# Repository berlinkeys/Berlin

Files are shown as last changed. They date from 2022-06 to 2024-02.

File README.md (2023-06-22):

# Berlin Keyboard

## Introduction
Berlin is a 120% Keyboard based on the design of the [Boston](https://github.com/bluepylons/Boston) keyboard. 
It has a lot of programmable Keys, runs QMK and all in all does everything you would like a keyboard to do.
It also features a big Display over the Numpad to enable more functions, like internal macros, status screens and custom graphics.

## Concept
The Inspiration for the Keyboard came directly from the Boston Keybaord. 
However, we wanted at least a 100% keyboard, including all the random keys only shady developers use.
Thats why we started redesigning the Boston, as it is both a good open source keyboard and a good starting point.
Dead space was never an option, so why not add an LCD instead of LED Indicators...

## Features
* 122-key in ISO configuration
* 127 local lighting zones
* 2 rotary encoders
* 3 SLIders
* optional lock LEDs 
* double sided and flippable debug connector
* Cherry MX Hotswap Ready
* Full-size Numpad
* Traditional 2x3 Ins/Del/Home/End/PgUp/PgDn navblock 
* Per Key RGBLED Lighting
* USB-C
* QMK and Vial support

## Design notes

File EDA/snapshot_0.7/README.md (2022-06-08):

# 0.7 dev version of PCB

***Important: This is a development branch of the keyboard. While in theory the PCB should work, something weird stuff called impedance and inductance always tries to mess up your projects. Also you wouldn't want this catching fire due to improper trace widths, would you? This is only v0.7 and due for a complete redesign. Don't be dumb, do not use this in prod (also not in testing for it is badly engineered).***

This directory is meant as a backup for the 0.7 version of the PCB. When the development on this version is complete, this will be deprecated and moved to branch ahead0.7.

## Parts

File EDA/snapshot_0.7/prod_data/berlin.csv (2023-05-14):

Comment | Designator | Footprint | LCSC
33 | R102,R101 | R_0805_2012Metric_Pad1.20x1.40mm_HandSolder | C328394
330 | R306,R307,R308 | R_Axial_DIN0207_L6.3mm_D2.5mm_P7.62mm_Horizontal | C17630
1.5A Polyfuse | F701 | Fuse_1812_4532Metric_Pad1.30x3.40mm_HandSolder | -
100 1% | R301,R703 | R_0805_2012Metric_Pad1.20x1.40mm_HandSolder | C17408
100k | R701 | R_0805_2012Metric_Pad1.20x1.40mm_HandSolder | C96346
100n | C707,C708,C725,C712,C102,C710,C727,C719,C101,C709,C723,C703,C721 | C_0805_2012Metric_Pad1.18x1.45mm_HandSolder | C2909631
100nF | C711 | C_0805_2012Metric_Pad1.18x1.45mm_HandSolder | C2909631
10k | R305,R302,R303,R304 | R_0805_2012Metric_Pad1.20x1.40mm_HandSolder | C17414
10u | C715,C724,C726,C706,C722,C720,C718 | C_1206_3216Metric_Pad1.33x1.80mm_HandSolder | C2985037
1M 1% | R702 | R_0805_2012Metric_Pad1.20x1.40mm_HandSolder | C17514
1N4148 | D43,D68,D105,D30,D83,D6,D35,D77,D10,D48,D103,D62,D93,D4,D63,D120,D9,D33,D31,D60,D91,D44,D110,D38,D84,D25,D53,D17,D51,D45,D59,D36,D119,D58,D47,D23,D111,D69,D126,D124,D2,D116,D99,D100,D125,D66,D19,D37,D80,D90,D61,D115,D32,D24,D28,D128,D75,D7,D113,D114,D64,D79,D107,D122,D94,D81,D74,D8,D5,D88,D21,D117,D26,D73,D82,D40,D98,D46,D56,D15,D41,D97,D67,D18,D87,D101,D112,D121,D96,D22,D78,D14,D57,D95,D13,D108,D54,D49,D16,D109,D118,D34,D106,D12,D39,D123,D76,D27,D703,D42,D71,D129,D104,D11,D89,D55,D85,D65,D92,D72,D70,D127,D52,D50,D3,D29,D20,D86 | D_SOD-123 | C14538
22uF | C717,C705,C701,C704 | C_1206_3216Metric_Pad1.33x1.80mm_HandSolder | C513771
330k 1% | R711 | R_0805_2012Metric_Pad1.20x1.40mm_HandSolder | C17629
4.7n | C714 | C_0805_2012Metric_Pad1.18x1.45mm_HandSolder | C1744
5.1k | R706,R705 | R_0805_2012Metric_Pad1.20x1.40mm_HandSolder | C27834
6.8uH | L701 | Sumida0624CDMCC | -
AP63203WU-7 | U702 | TSOT-23-6_HandSoldering | C780769
DTC123J | Q701 | SOT-23 | C2910218
L_Core_Ferrite | L1,L2,L702,L711 | L_0805_2012Metric_Pad1.15x1.40mm_HandSolder | C139247
LQFP100 | U501 | STM32F072VBT6 | C713240
MountingHole | HA201,HA204,HA202,HA203 | ToolingHole_1.152mm_(for_JLCPCB_SMT)
RB060M-60TR | D701 | D_SOD-123 | C114257
TE_2-84953-0_1x20-1MP_P1.0mm_Horizontal | J203 | TE_2-84953-0_1x20-1MP_P1.0mm_Horizontal | C362389
TYPE-C-31-M12_13 | J201 | TYPE-C-31-M-12 | C165948
USBLC6-2SC6 | U701 | SOT-23-6 | C2827654
WS2811 | LED1,16,LED1,1 | WS2811S | C3034986
WS2812B | LED3,11,LED3,2,LED7,5,LED2,10,LED3,6,LED2,8,LED7,2,LED1,7,LED1,2,LED4,8,LED5,11,LED1,6,LED7,7,LED4,5,LED3,7,LED7,6,LED5,14,LED6,9,LED1,10,LED5,9,LED3,17,LED5,2,LED2,14,LED1,5,LED3,16,LED3,15,LED4,11,LED2,9,LED4,14,LED3,8,LED2,4,LED7,1,LED4,18,LED3,10,LED4,4,LED1,11,LED4,1,LED2,19,LED1,4,LED3,18,LED5,1,LED3,4,LED4,6,LED4,15,LED6,8,LED5,7,LED6,18,LED6,15,LED4,2,LED7,15,LED6,12,LED6,3,LED4,10,LED5,15,LED4,13,LED4,12,LED4,16,LED7,3,LED2,18,LED5,10,LED7,18,LED7,16,LED1,9,LED4,19,LED2,17,LED7,17,LED6,19,LED5,8,LED3,19,LED7,13,LED5,19,LED2,11,LED6,4,LED5,13,LED5,16,LED6,16,LED5,12,LED6,6,LED2,16,LED6,2,LED1,12,LED6,1,LED7,9,LED5,3,LED2,7,LED3,1,LED6,17,LED6,14,LED2,13,LED4,3,LED2,5,LED3,12,LED6,13,LED7,14,LED2,1,LED1,13,LED1,3,LED3,5,LED7,12,LED4,17,LED3,14,LED5,4,LED7,8,LED5,5,LED4,9,LED2,3,LED7,10,LED4,7,LED5,17,LED2,12,LED3,13,LED6,10,LED6,5,LED2,6,LED6,11,LED1,15,LED7,11,LED3,3,LED5,6,LED1,14,LED1,8,LED6,7,LED2,15,LED3,9,LED5,18,LED2,2 | SK6812MINI_3535_6028_3.2x2.8mm_Round | C5149201

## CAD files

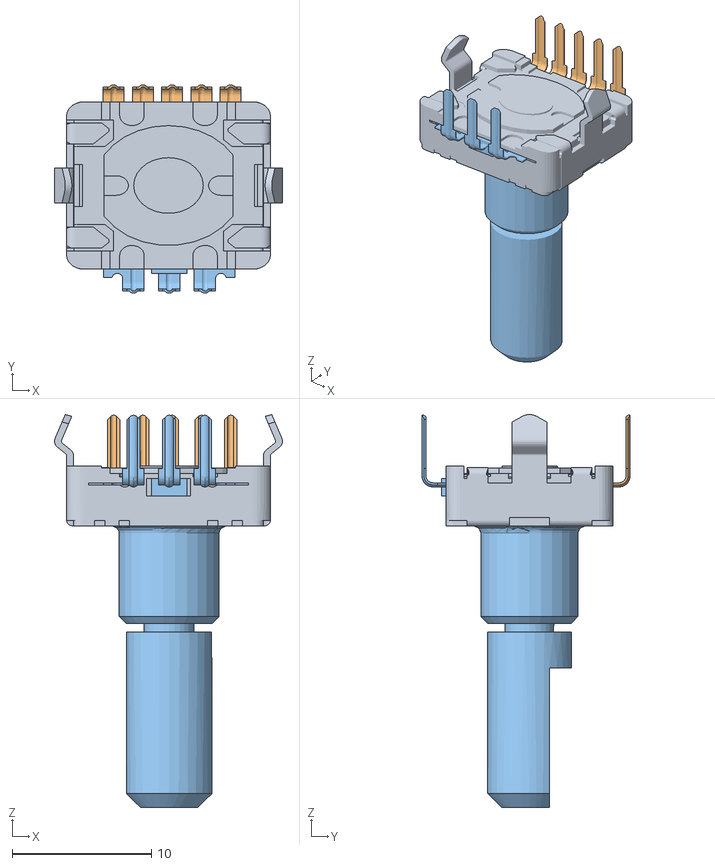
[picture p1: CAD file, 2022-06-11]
EDA/ressources/acheron_3d_models/EC12PSD-LED.obj
16.4 x 14.9 x 28.2
EC12PSD-LED
EC12PSD-LED.001
EC12PSD-LED.002

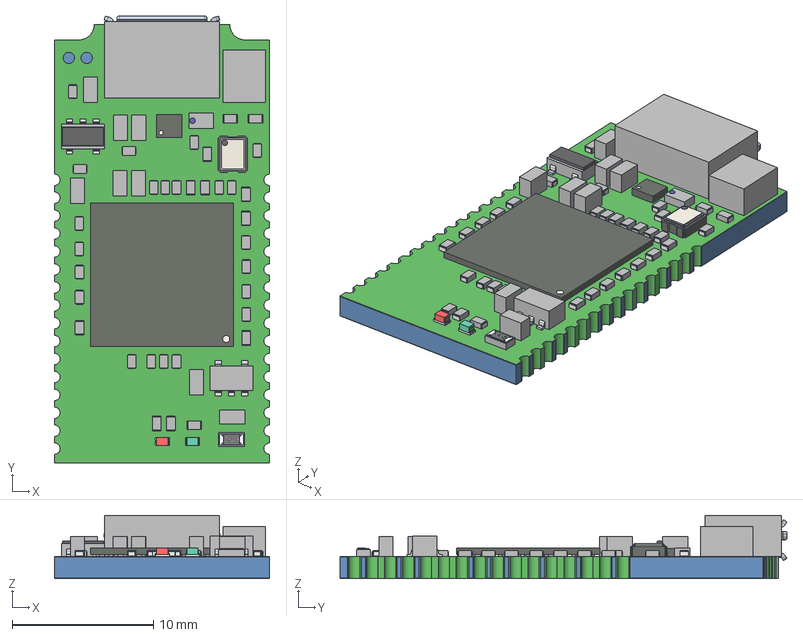
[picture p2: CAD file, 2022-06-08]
EDA/ressources/stlink/STLINK-V3MODS.step
15.2 x 31.7 x 4.47 mm
Board
LED0402_greenH05
Extruded x 59
R0402 x 12
C0402 x 22
C0603 x 8
SOT23-5L x 2
LED0402_redH05
R0603

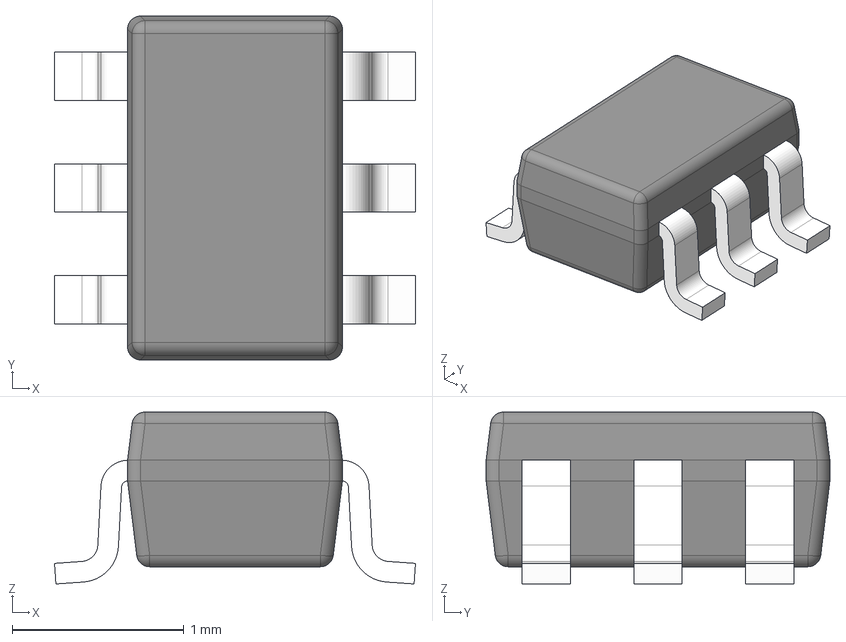
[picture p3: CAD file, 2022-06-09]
EDA/ressources/ul_SN74LVC1T45DCKR/DCK0006A.stp
2.10 x 2.00 x 1.00 mm
BODY-SOT
LEAD-SOT x 6
PIN1-ID

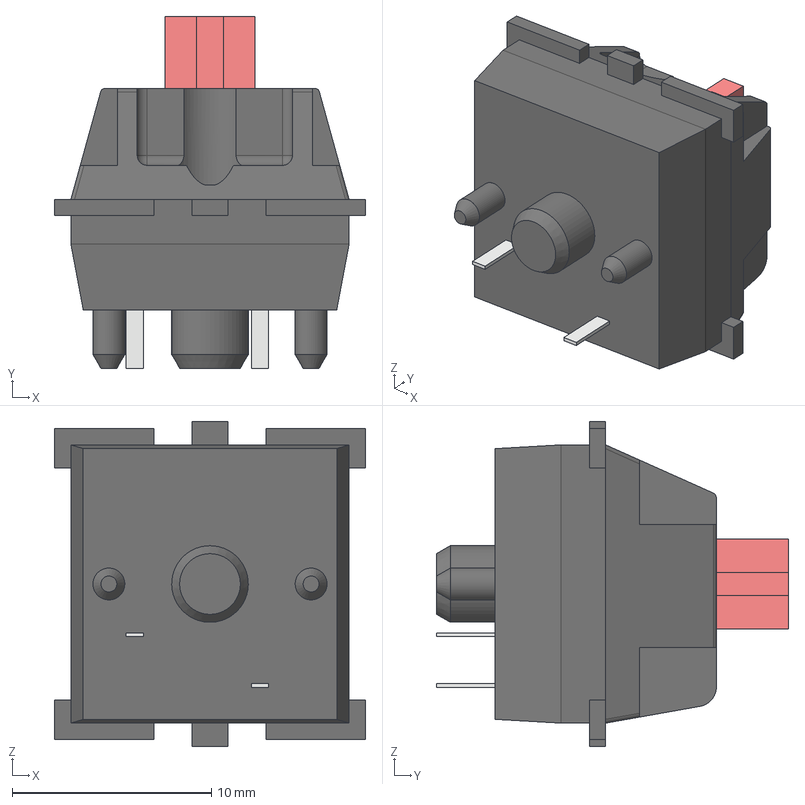
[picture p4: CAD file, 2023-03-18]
EDA/snapshot_0.7/3d/mx-switch.step
15.6 x 17.7 x 16.3 mm

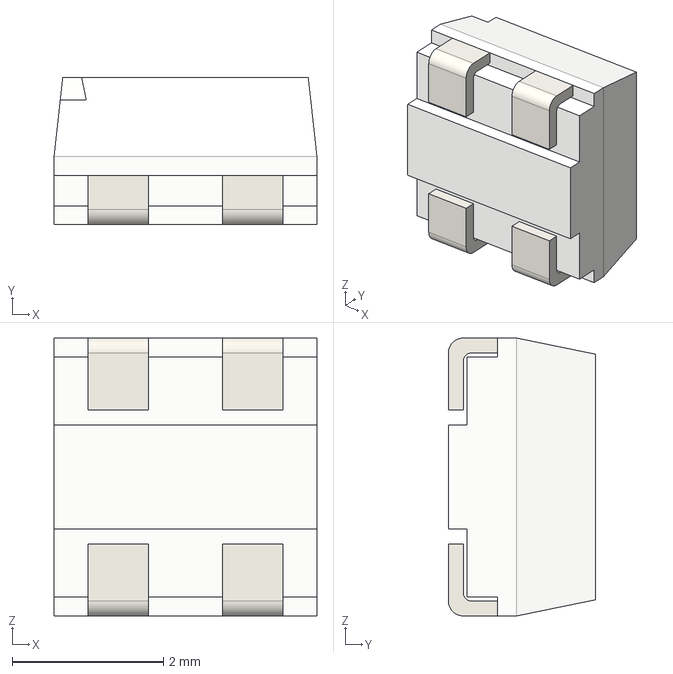
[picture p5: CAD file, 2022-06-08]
EDA/ressources/acheron_3d_models/WS2812-Mini.step
3.48 x 1.95 x 3.68 mm

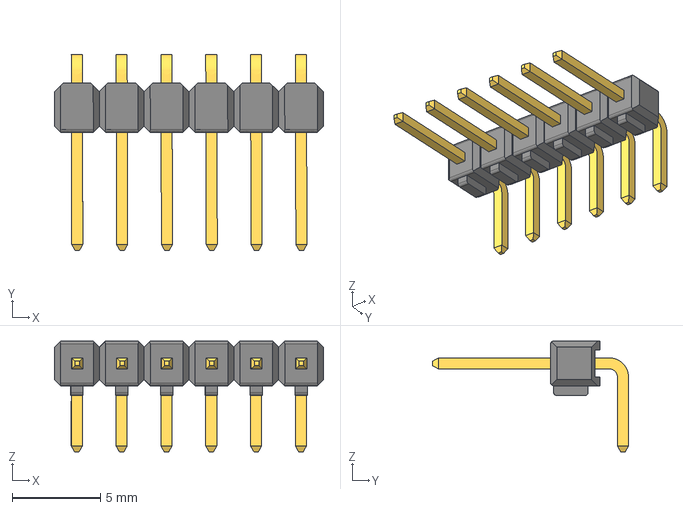
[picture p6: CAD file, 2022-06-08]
EDA/ressources/acheron_3d_models/angle6PinHeader.stp
15.2 x 11.1 x 6.29 mm

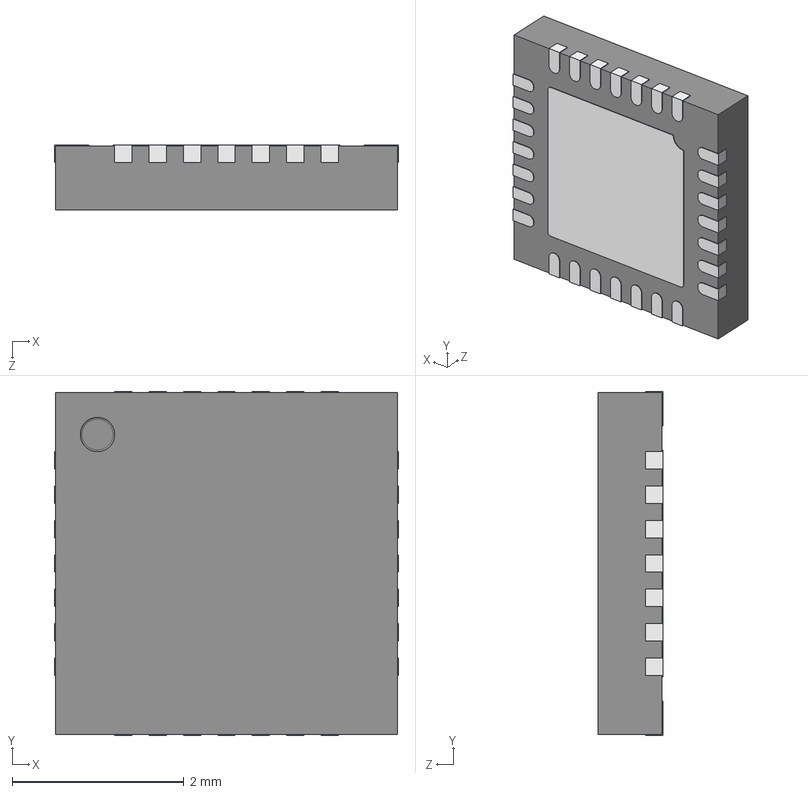
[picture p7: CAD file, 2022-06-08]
EDA/ressources/acheron_3d_models/QFN28-P0.4mm.step
4.00 x 4.00 x 0.75 mm
Free-Models
Free-Models016
Free-Models026
Free-Models027
Free-Models028
Free-Models009
Free-Models008
Free-Models007
Free-Models022
Free-Models023
Free-Models001
Free-Models003
Free-Models002
Free-Models024
Free-Models025
Free-Models014
Free-Models013
Free-Models015
Free-Models017
Free-Models018
Free-Models020
Free-Models021
Free-Models019
Free-Models005
Free-Models004
Free-Models006
Free-Models012
Free-Models011
Free-Models010

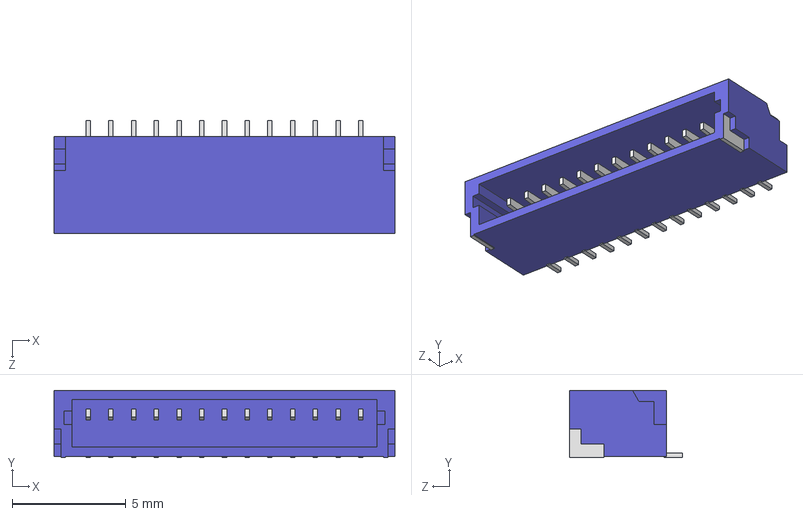
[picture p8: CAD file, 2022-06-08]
EDA/ressources/acheron_3d_models/SM13B-SRSS-TB.STEP
15.0 x 2.96 x 4.95 mm

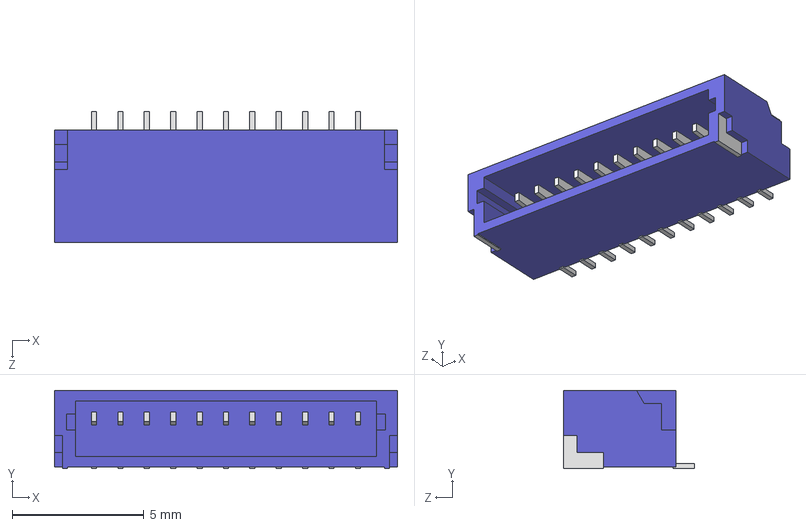
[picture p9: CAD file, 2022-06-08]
EDA/ressources/acheron_3d_models/SM11B-SRSS-TB.STEP
13.0 x 2.96 x 4.95 mm

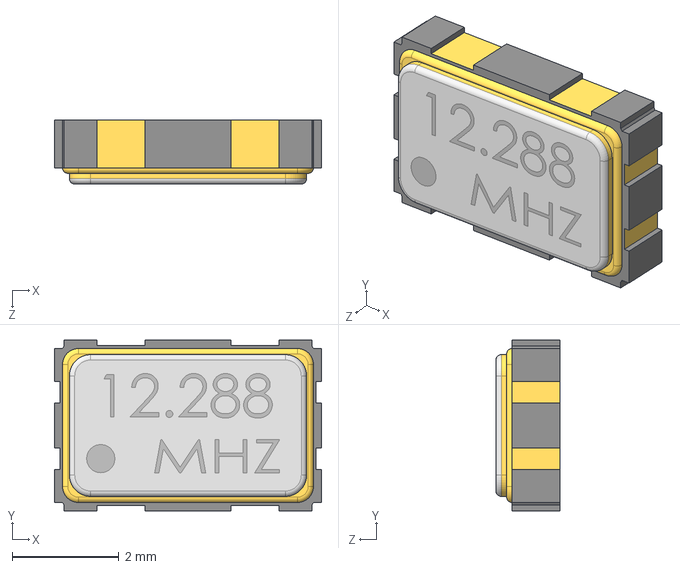
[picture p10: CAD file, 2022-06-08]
EDA/ressources/acheron_3d_models/OSC5032.STEP
5.00 x 3.20 x 1.20 mm

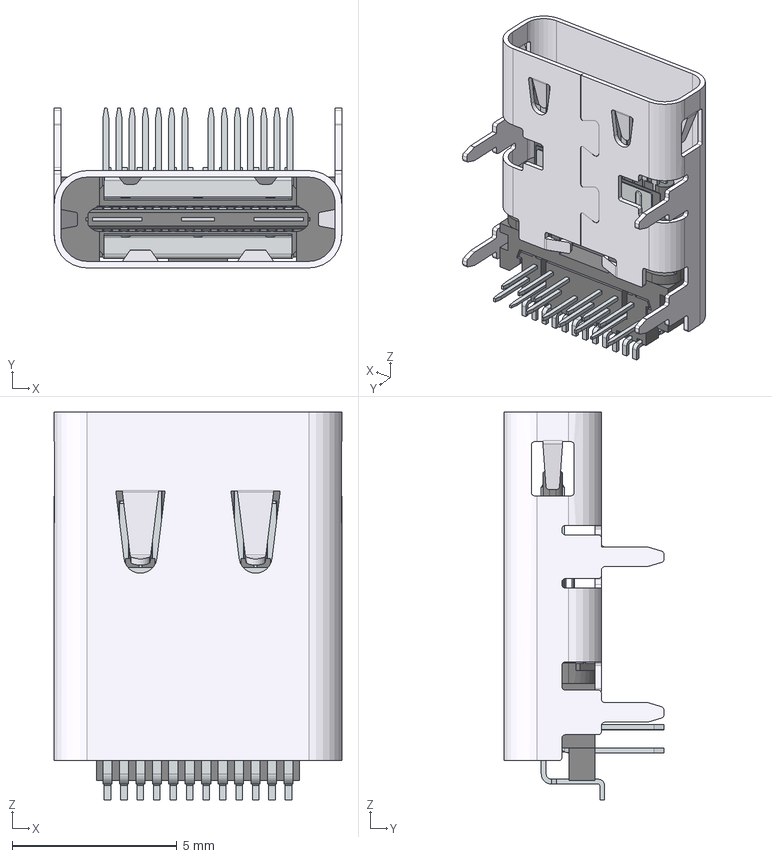
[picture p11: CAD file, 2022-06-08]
EDA/ressources/acheron_3d_models/wurth_632723300011.stp
8.74 x 4.86 x 11.8 mm
632723300011_Housing
632723300011_Shielding_3_v3
632723300011_PIN2_Top_v3 x 8
632723300011_Housing_TOP
632723300011_Shielding_1_v3
632723300011_PIN1_Top_v3 x 4
632723300011_Housing_Bottom
632723300011_PIN1_Bottom_v3
632723300011_PIN2_Bottom_v3
632723300011_PIN4_Bottom_v3
632723300011_PIN5_Bottom_v3
632723300011_PIN6_Bottom_v3
632723300011_PIN7_Bottom_v3
632723300011_Shielding_2 x 2
632723300011_PIN1_Bottom_v3_mir
632723300011_PIN4_Bottom_v3_mir
632723300011_PIN6_Bottom_v3_mir
632723300011_PIN2_Bottom_v3_mir
632723300011_PIN5_Bottom_v3_mir
632723300011_PIN7_Bottom_v3_mir
632723300011_Housing_Bottom3

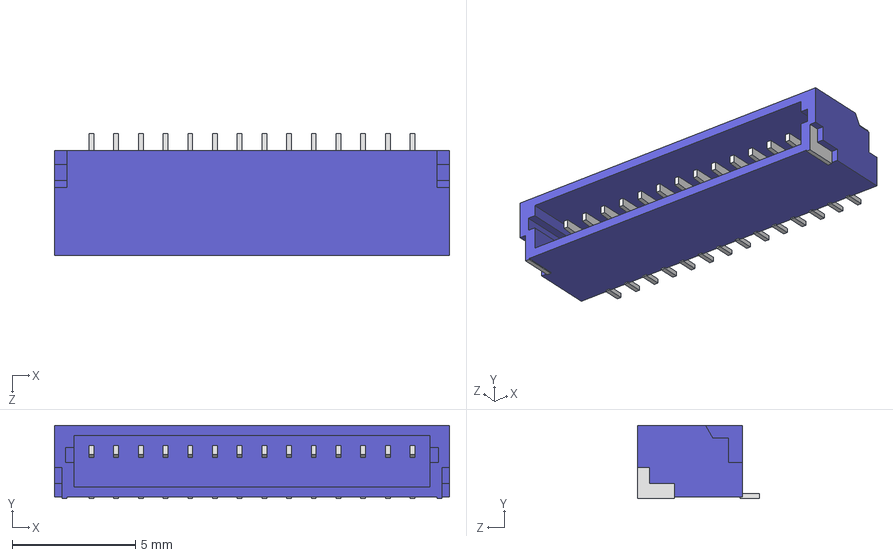
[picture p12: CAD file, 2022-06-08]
EDA/ressources/acheron_3d_models/SM14B-SRSS-TB.STEP
16.0 x 2.96 x 4.95 mm

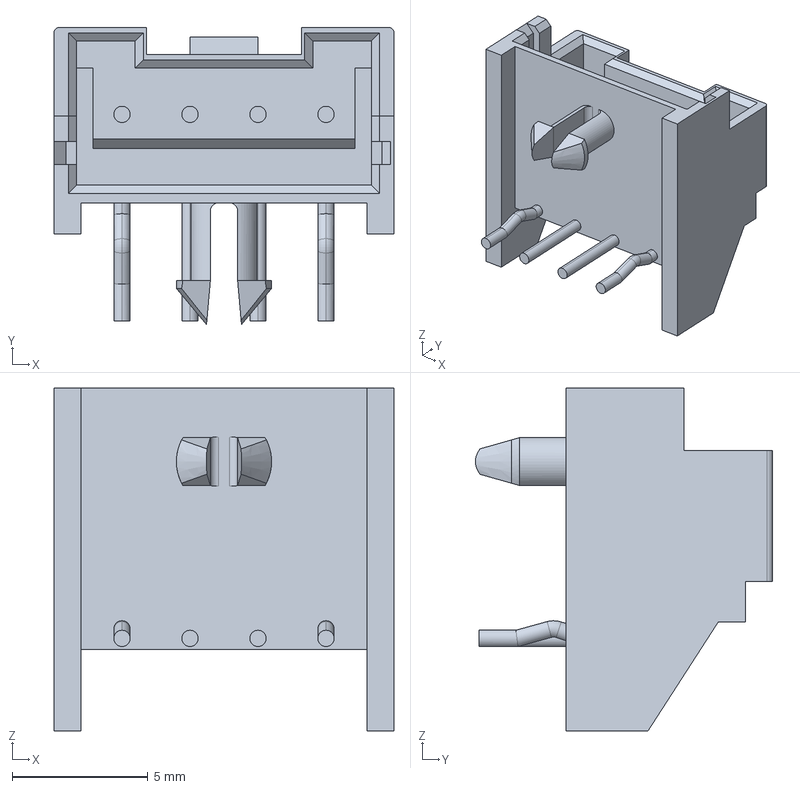
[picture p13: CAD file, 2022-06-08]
EDA/ressources/acheron_3d_models/TE-1744426-4.stp
12.5 x 10.9 x 12.6 mm

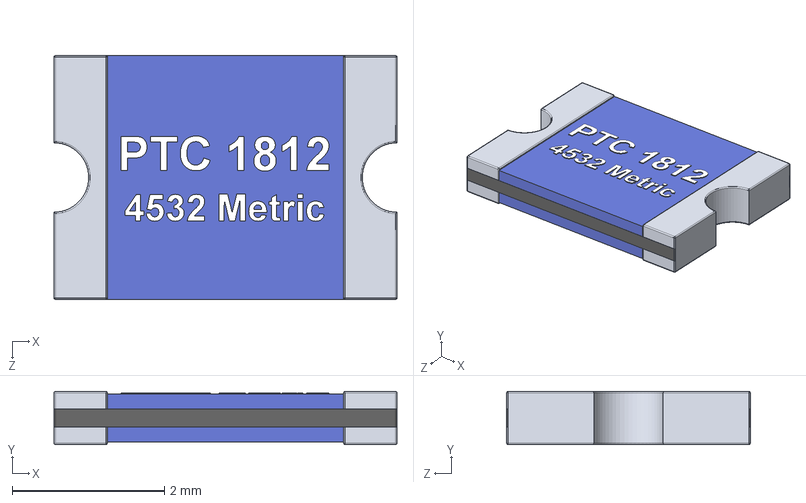
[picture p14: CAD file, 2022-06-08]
EDA/ressources/acheron_3d_models/FUSE_1812.STEP
4.50 x 0.7 x 3.20 mm

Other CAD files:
EDA/ressources/acheron_3d_models/BM04B-ASRS-TF.STEP
EDA/ressources/acheron_3d_models/XM7D-0512.STEP
EDA/ressources/acheron_3d_models/MDBT40.step
EDA/ressources/acheron_3d_models/5032_XTAL.step
EDA/ressources/acheron_3d_models/3313J-1-202E.stp
EDA/ressources/acheron_3d_models/4PinHeader.step
EDA/ressources/acheron_3d_models/6028SMDRGB.iges
EDA/ressources/acheron_3d_models/9774010243.stp
EDA/ressources/acheron_3d_models/9774030243R.step
EDA/ressources/acheron_3d_models/ACM2012-2P.STEP
EDA/ressources/acheron_3d_models/ALPS_EC11E.stp
EDA/ressources/acheron_3d_models/BM04B-SRSS.step
EDA/ressources/acheron_3d_models/E6C1209RGB.iges
EDA/ressources/acheron_3d_models/RKJXT1F42001.step
EDA/ressources/acheron_3d_models/SM04B-SRSS-TB.STEP
EDA/ressources/acheron_3d_models/SM05B-SRSS-TB.STEP
EDA/ressources/acheron_3d_models/SM20B-SRSS-TB.STEP
EDA/ressources/acheron_3d_models/TE-2132415-4.stp
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

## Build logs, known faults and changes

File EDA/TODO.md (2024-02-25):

# Todo

All changes to implement for future design iterations of the keyboard

## Components

- redo programming circuit
	- minimalise header
	- rethink buttons
- reconsider status leds / position
	- (make rgb?)
- use ws2811 in sop-8 instead of msop-8
- reconsider display wiring / quad spi
- multilayout switch configuration (e.g. spacebar)

- flipped rotary encoder footprint
- use bigger pads for sk6812 rgbleds -> easier soldering (likely switch footprint)
- different mounting holes/better spacing and positioning

- redo 3v3 circuit to eliminate coil whine
- upgrade polyfuse
- proper power budget & trace width calc

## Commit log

2021-09-07 clean up the key matrix
    [berlin.kicad_sch]
2021-09-07 blursed schematic
    [berlin.kicad_sch]
2021-09-07 added additional schematics
    [berlin.kicad_sch]
2021-09-08 initial pcb layouting
    [berlin.kicad_pcb]
2021-09-08 update gitignore and remove unnecessary switches
    [berlin.kicad_pcb]
2021-09-08 bruder muss los
    [berlin.kicad_pcb]
2021-09-08 update/fix switch descriptors
    [berlin.kicad_pcb, berlin.kicad_sch]
2021-09-09 added lqfp100 chip
    [berlin.kicad_sch]
2021-09-09 Add DOGXL LCD to PCB
    [berlin.kicad_pcb]
2021-09-09 initial pinout placement
    [berlin.kicad_sch]
2021-09-09 add hotswap switches
    [berlin.kicad_pcb]
2021-09-09 layout pcb rows
    [berlin.kicad_sch]
2021-09-10 Add missing column traces and connect row 3
2021-09-10 add some pcb design best practices
    [berlin.kicad_sch]
2021-09-10 add stlink library and symbol
    [STLINK-V3MODS.step, berlin.kicad_sch]
2021-09-12 route first usb/kb nets
    [berlin.kicad_sch]
2021-09-14 morte routing than the telekom will ever do
    [berlin.kicad_pcb]
2021-09-14 still a better lovestory than twilight
    [berlin.kicad_pcb]
2021-09-16 update col traces
    [berlin.kicad_pcb]
2021-09-17 update neopixels to reverse mount
    [berlin.kicad_pcb]
2021-09-18 resolve drc conflicts
    [berlin.kicad_pcb]
2021-09-18 more routing
    [berlin.kicad_pcb, berlin.kicad_sch]
2021-09-19 route jtag and last key traces
    [berlin.kicad_pcb, berlin.kicad_sch]
2021-09-22 update drc
    [berlin.kicad_pcb]
2021-11-17 small updates in naming/routing
    [berlin.kicad_pcb, berlin.kicad_sch]
2021-12-14 Insert auxiliary components for ICs
    [berlin.kicad_sch]
2021-12-14 update KiCAD to Nightly 25643.
    [berlin.kicad_sch]
2021-12-14 new routing, active parts and ground planes
    [berlin.kicad_sch]
2021-12-15 add additional reset components and power traces
    [berlin.kicad_sch]
2021-12-16 fix led placement and DRC
2022-03-26 misc changes
    [berlin.kicad_sch]
2022-03-27 annotated diodes next to switches
    [berlin.kicad_sch]
2022-03-27 rename some leds
2022-03-27 Rename all LEDs to match Switch Matrix Positions
2022-03-27 add/refactor custom CAD libraries
    [MSOP8_WDS.step, STLINK-V3MODS.step]
2022-03-27 footprint mods
2022-03-28 update rotary encoders
2022-03-28 fix rotary encoders
    [berlin.kicad_sch]
2022-03-28 fix inductor/switch overlap and power planes
2022-03-29 update to FT io and LED update
    [berlin.kicad_sch]
2022-03-31 fix glitchy matrix design
    [berlin.kicad_sch]
2022-03-31 minor led additions
    [berlin.kicad_sch]
2022-04-01 reformatting/reannotation, add new display mockup
    [berlin.kicad_sch]
2022-04-03 add&annotate all leds
    [berlin.kicad_sch]
2022-04-03 minor led changes
    [berlin.kicad_sch]
2022-04-03 Route first two rows of LEDs
    [berlin.kicad_sch]
2022-04-04 fix routing of leds 2,17-19
2022-04-04 route led row 4
2022-04-04 route led row 5
2022-04-04 route led row 6
2022-04-04 finish routing all LEDs
2022-04-06 update disp connector position
2022-04-18 Fix LED Data net association and ground planes
2022-04-20 power routing & cleanup
2022-04-21 common rail led power routing
2022-05-03 more power routing & DRC
2022-05-05 routing & addition of trace thicc calculation sheet
    [leitungsdicken.ods]
2022-05-05 add plugin for grounding and optimizations
2022-05-08 add acheron3d, route bottom sectors
    [3313J-1-202E.stp, 4PinHeader.step, 5032_XTAL.step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]
2022-05-29 Add LCD Connector to Schematic
    [berlin.kicad_sch]
2022-05-29 reroute usb+disp
    [berlin.kicad_sch]
2022-05-30 Clean up schematic LCD Connector Voltage rail rotation
    [berlin.kicad_sch]
2022-05-30 Update PCB to remove Unneeded VIAs on pwin
2022-06-01 Add Vias to Connect GND planes
    [berlin.kicad_sch]
2022-06-01 Connect 5V net using traces and VIAs
2022-06-01 Set all NETS on the LEDS to 5V and GND
2022-06-06 5V routing and small positional fixes
2022-06-06 route last LED 5V; fix DRC; add lock leds
2022-06-08 misc additions/corrections to schema
    [berlin.kicad_sch]
2022-06-08 refactor to use copied version of kicad proj
    [berlin.kicad_sch]
2022-06-09 add sn74 and bug fixes
    [DCK0006A.stp, berlin.kicad_sch]
2022-06-10 update mcu connections for potentiometers and rgb leds
    [berlin.kicad_sch]
2022-06-10 add lock led & rot enc conns & make parity test ready
    [berlin.kicad_sch]
2022-06-11 mitigate ~500 parity and other errors
    [berlin.kicad_sch]
2022-06-11 add/correct 3d models
    [EC12PSD-LED.obj]
2022-06-11 correct more footprint ids in 0.7
2022-07-23 add 0.6 ref, upd plugin files
    [Boston-keyboard-V06.kicad_sch]
2022-08-02 upd ground to skynet script
2022-08-07 upd .7 w/ last logic routing
    [berlin.kicad_sch]
2022-08-07 0.7: add power caps&footprints
    [berlin.kicad_sch]
2022-08-08 0.7: add second res button; bugfixes
    [berlin.kicad_sch]
2022-08-08 0.7: export first gerber
    [berlin-User_Comments.gbr, berlin-User_Drawings.gbr]
2022-08-08 append last
    [berlin-User_Comments.gbr, berlin-User_Drawings.gbr]
2022-12-03 fix 0.7 DRC issues, DRC rules
    [berlin.kicad_sch]
2022-12-03 0.7 add mounting holes & branding
    [berlin.kicad_sch]
2022-12-03 0.7 add design/manufacturing files
    [berlin-B_Cu.gbl, berlin-B_Mask.gbs, berlin-B_Paste.gbp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]
2022-12-03 Fix LED Mask
2022-12-04 Add two more switches for fun
    [berlin.kicad_sch]
2022-12-04 append last 2 commits to comply with standards
    [berlin.kicad_sch]
2022-12-04 update grb/production files
    [berlin-B_Cu.gbl, berlin-B_Mask.gbs, berlin-B_Paste.gbp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]
2022-12-09 add flipped programming connector
2022-12-11 0.7 add mangly mounting points
2023-01-09 Fix 3 Row Header, add Model for USB Filter
    [berlin.kicad_sch]
2023-01-09 fix connector spacing
2023-01-11 Modify footprint of debug conenctor for better legibility
2023-01-11 upd production files
    [berlin-B_Cu.gbl, berlin-B_Mask.gbs, berlin-B_Paste.gbp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]
2023-01-11 upd manufacturing.zip
    [berlin-B_Cu.gbl, berlin-B_Mask.gbs, berlin-B_Paste.gbp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]
2023-03-26 Add JLC manufacturing data with JLC Plugin
    [berlin-B_Cu.gbl, berlin-B_Mask.gbs, berlin-B_Paste.gbp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]
2023-05-14 mv boston into ressources
    [Boston-keyboard-V06.kicad_sch]
2023-06-22 add missing traces for switch 7,7; 7,13; 6,14; 6,16
2023-06-23 Fix schematic: The selected rotary encoder is weird. This is the actual design we are building.
    [berlin.kicad_sch]
